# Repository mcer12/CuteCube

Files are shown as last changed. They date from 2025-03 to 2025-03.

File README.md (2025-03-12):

## About the project
This is a little cube toy with leds that changes color depending on which side it's laid on. Kids love it and it can be used for decision making (just kidding), desk games etc. It uses accelerometer to detect orientation and if you shake it, it does a random color animation. With 350mAh battery it lasts for about 2 weeks depending on use.  



## Important notes
- Letting toddlers play with this is at your own risk!
- you can use BMI055 or BMI088, make sure to select correct one in the sketch as they have different instruction sets
- Use my fork of the libraries to allow low power (gyro sleep):  
BMI088: https://github.com/mcer12/bmi088-arduino  
BMI055: https://github.com/mcer12/FastIMU  
- If you want to enable easy flashing via USB (serial), you need to set nBOOT_SEL fuse to 0: BOOT0 signal is defined by BOOT0 pin value (legacy mode)
- Forgive the code quality, it was a quick arduino project, not meant to be published and I'm NOT cleaning that up :D

## Printing notes
- No supports needed
- Transparent PLA or PETG highly recommended.
- Two size variants (55x55mm and 67x67mm)
- Requires two long M3 bols and two hot melt inserts.
- Bolts: I used 25mm 
- Inserts: OD4.5mm, 10mm length. You don't need to use inserts this long but they make it pretty much indestructible.

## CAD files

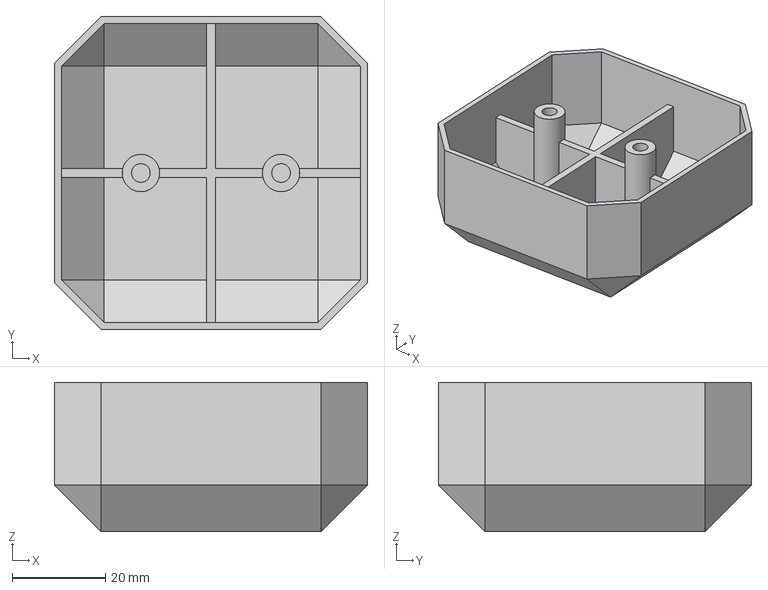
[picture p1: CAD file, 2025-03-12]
3D/cube_larger_bottom.3mf
67.0 x 67.0 x 32.0 mm

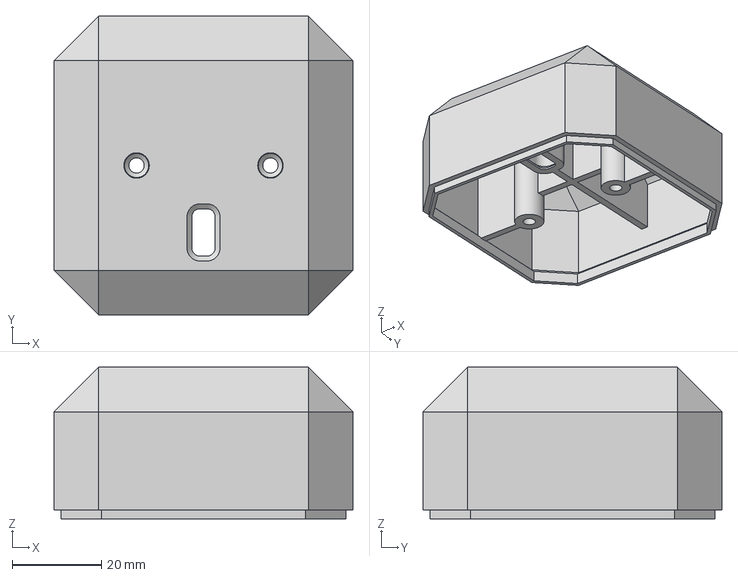
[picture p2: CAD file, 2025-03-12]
3D/cube_larger_top.3mf
67.0 x 67.0 x 34.0 mm

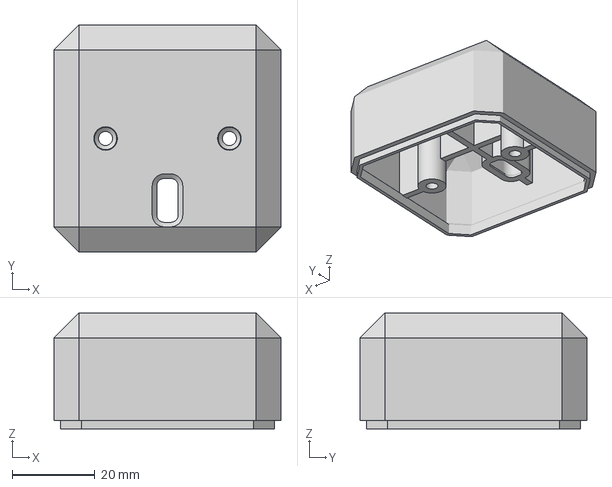
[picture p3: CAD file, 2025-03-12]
3D/cube_top.3mf
55.0 x 55.0 x 28.0 mm

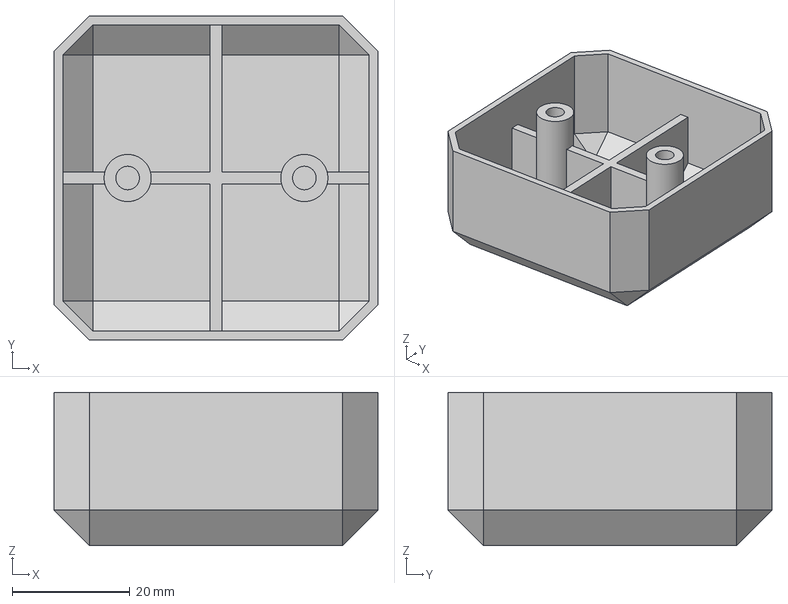
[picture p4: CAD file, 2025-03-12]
3D/cube_bottom.3mf
55.0 x 55.0 x 26.0 mm

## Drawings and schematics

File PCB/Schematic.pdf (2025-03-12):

TIM17: PA7, PA10, PD1, PB4, PB7, PB9,

## TIM16: PA6, PB6, PB8

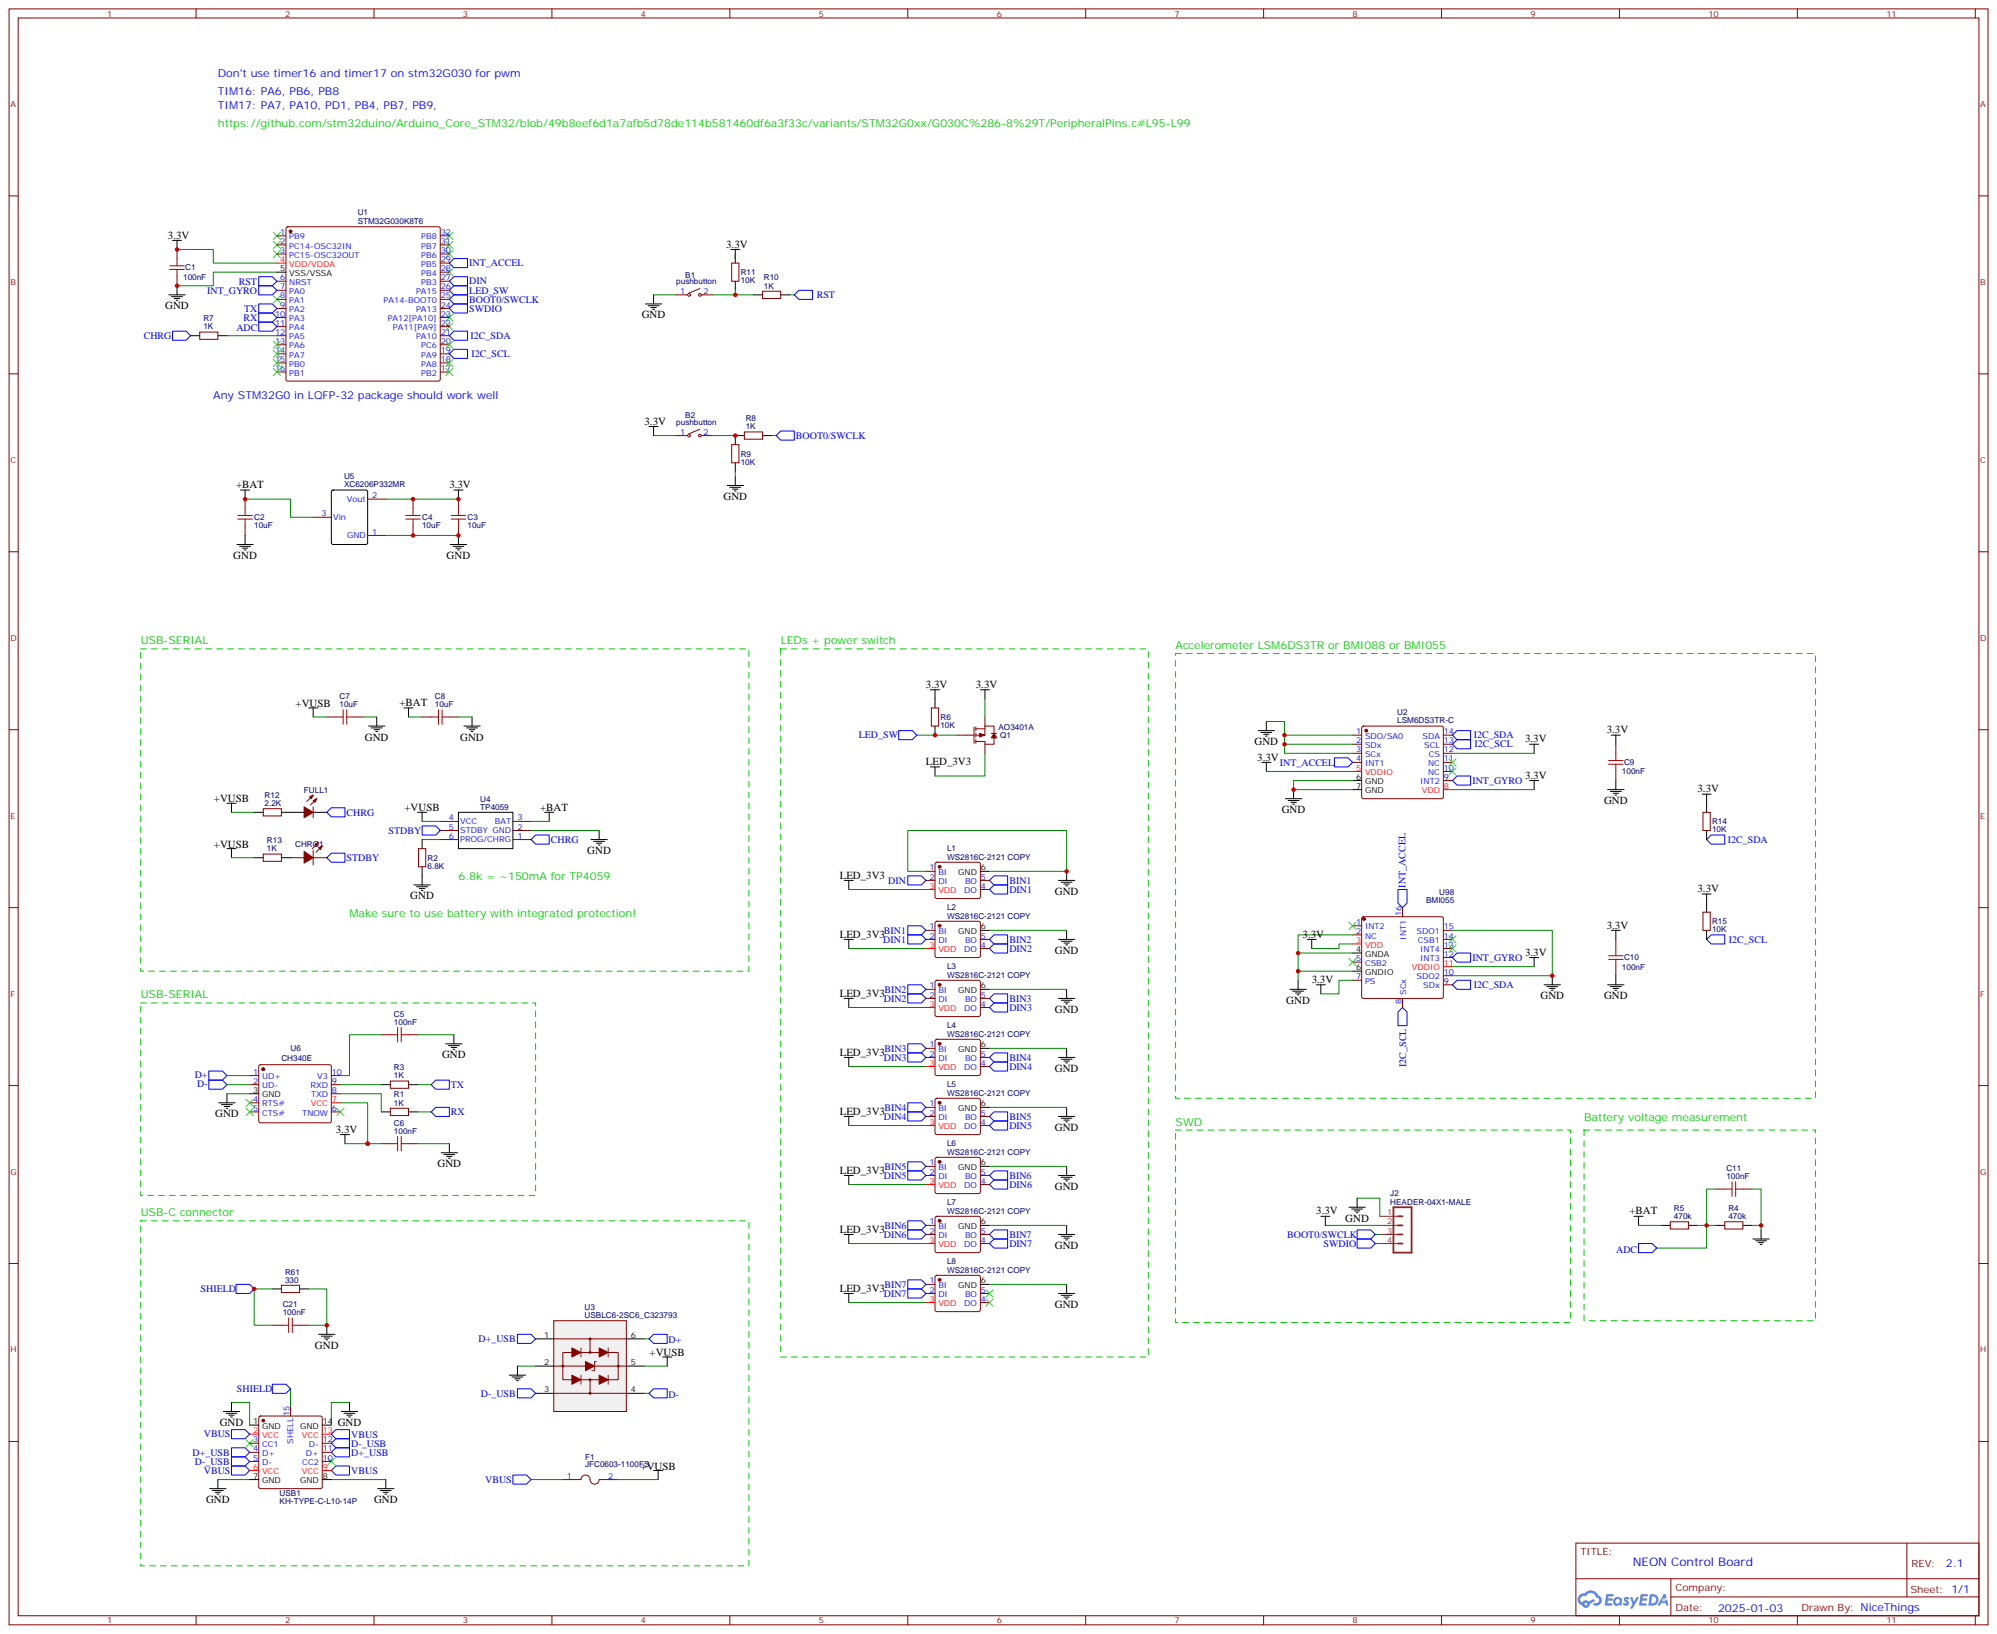
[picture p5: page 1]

Don't use timer16 and timer17 on stm32G030 for pwm

https://github.com/stm32duino/Arduino_Core_STM32/blob/49b8eef6d1a7afb5d78de114b581460df6a3f33c/variants/STM32G0xx/G030C%286-8%29T/PeripheralPins.c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

Any STM32G0 in LQFP-32 package should work well

Make sure to use battery with integrated protection!

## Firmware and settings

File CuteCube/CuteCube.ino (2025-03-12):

//#define USE_BMI088
#define DEBUG_ENABLE
#define ACCEL_ADDRESS 0x18
#define GYRO_ADDRESS 0x68
#define LED_PIN PB3
#define LED_EN PA15
#define NUM_LEDS 8
#define SLEEP_TIMEOUT_SECONDS 20
#define ADC_PIN PA4
#define CHRG_PIN PA5

#include <Wire.h>
#include "WS2816_Driver.h"
#include "STM32LowPower.h"

#ifdef USE_BMI088
#include "BMI088.h"
#else
#include "FastIMU.h"
#endif

#ifdef USE_BMI088
Bmi088Accel accel(Wire, ACCEL_ADDRESS);
Bmi088Gyro gyro(Wire, GYRO_ADDRESS);
#else
BMI055 IMU;
calData calib = { 0 };  //Calibration data
AccelData accelData;    //Sensor data
GyroData gyroData;
#endif

float accelX, accelY, accelZ, gyroX, gyroY, gyroZ, temp, voltage;
bool isCharging = false;
uint8_t orientation = 0;
unsigned long sleepTimer, shuffleTimer, shortShuffleTimer;
uint8_t shuffleCounter, shuffleCounterSuccess, shortShuffleCounter, shortShuffleCounterSuccess;
int bri = 40000;
int extraR = 0;
int extraG = 0;
int extraB = 0;
bool activity, wentToSleep = false;

WS2816_Driver strip(NUM_LEDS, LED_PIN);

void setup() {
  Serial.begin(115200);

  analogReadResolution(12);
  pinMode(ADC_PIN, INPUT);
  pinMode(CHRG_PIN, INPUT);
  pinMode(LED_EN, OUTPUT);
  setLedsPower(true);
  randomSeed(analogRead(ADC_PIN));
  delay(5);

  strip.begin();
  strip.clear();
  strip.show();

  delay(100);

  initSensor();

  LowPower.begin();
  sleepTimer = shuffleTimer = millis();

}


void loop() {
  readData();

  if (voltage < 3.4 && !wentToSleep) {
    handleLowBattery();
    setLedsPower(false);
#ifdef DEBUG_ENABLE
    Serial.println("low battery, going to sleep!");
    delay(20);
#endif
    LowPower.deepSleep(3000);
  }

  if (millis() - shuffleTimer > 100) {
    shuffleTimer = millis();
    shuffleCounter++;
    if (accelX > 20.0 || accelY > 20.0 || accelZ > 20.0) {
      shuffleCounterSuccess++;
    }
    if (shuffleCounter >= 10) {
      if (shuffleCounterSuccess >= 3) {
        handleShuffle();
        triggerActivity();
        orientation = -1;
      }
      shuffleCounter = shuffleCounterSuccess = 0;
    }
  }

  /*
    if (millis() - shortShuffleTimer > 50) {
      shortShuffleTimer = millis();
      shortShuffleCounter++;
      if (accelX > 15.0 || accelY > 15.0 || accelZ > 15.0) {
        shortShuffleCounterSuccess++;
      }
      if (shortShuffleCounter >= 30) {
        if (shortShuffleCounterSuccess >= 10) {
          handleShortShuffle();
        }
        shortShuffleCounter = shortShuffleCounterSuccess = 0;
      }
    }
  */

  if (accelX < -9.6 && orientation != 0) {
    orientation = 0;
    handleOrientation(orientation);
    triggerActivity();
    //strip.setPixelColor(0, 100, 0, 0);
    //strip.setPixelColor(1, 100, 0, 0);
    //strip.setPixelColor(2, 100, 0, 0);
    //strip.setPixelColor(3, 100, 0, 0);
  }
  if (accelX > 9.6 && orientation != 1) {
    orientation = 1;
    handleOrientation(orientation);
    triggerActivity();
    //strip.setPixelColor(4, 100, 0, 0);
    //strip.setPixelColor(5, 100, 0, 0);
    //strip.setPixelColor(6, 100, 0, 0);
    //strip.setPixelColor(7, 100, 0, 0);
  }
  if (accelY > 9.6 && orientation != 2) {
    orientation = 2;
    handleOrientation(orientation);
    triggerActivity();
    //strip.setPixelColor(0, 100, 0, 0);
    //strip.setPixelColor(1, 100, 0, 0);
    //strip.setPixelColor(6, 100, 0, 0);
    //strip.setPixelColor(7, 100, 0, 0);
  }
  if (accelY < -9.6 && orientation != 3) {
    orientation = 3;
    handleOrientation(orientation);
    triggerActivity();
    //strip.setPixelColor(2, 100, 0, 0);
    //strip.setPixelColor(3, 100, 0, 0);
    //strip.setPixelColor(4, 100, 0, 0);
    //strip.setPixelColor(5, 100, 0, 0);
  }
  if (accelZ > 9.6 && orientation != 4) {
    orientation = 4;
    handleOrientation(orientation);
    triggerActivity();
    //strip.setPixelColor(0, 100, 0, 0);
    //strip.setPixelColor(2, 100, 0, 0);
    //strip.setPixelColor(4, 100, 0, 0);
    //strip.setPixelColor(6, 100, 0, 0);
  }
  if (accelZ < -9.6 && orientation != 5) {
    orientation = 5;
    handleOrientation(orientation);
    triggerActivity();
    //strip.setPixelColor(1, 100, 0, 0);
    //strip.setPixelColor(3, 100, 0, 0);
    //strip.setPixelColor(5, 100, 0, 0);
    //strip.setPixelColor(7, 100, 0, 0);
  }


  if (millis() - sleepTimer > 30000) {
    //sleepTimer = millis();
    wentToSleep = true;
    setLedsPower(false);
#ifdef DEBUG_ENABLE
    Serial.println("no action, going to sleep!");
    delay(20);
#endif
    LowPower.deepSleep(3000);
  }

#ifdef DEBUG_ENABLE
  delay(10);
#else
  LowPower.deepSleep(20);
#endif

}

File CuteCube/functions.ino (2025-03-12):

void initSensor() {
#ifdef USE_BMI088
  int status;
  status = accel.begin();
  if (status < 0) {
    Serial.println("Accel Initialization Error");
    Serial.println(status);
    while (1) {}
  }
  status = gyro.begin();
  if (status < 0) {
    Serial.println("Gyro Initialization Error");
    Serial.println(status);
    while (1) {}
  }
  //accel.setMode(false);
  //accel.setPower(false);
  gyro.writeRegister(0x11, 0b10000000);
#else
  Wire.begin();
  Wire.setClock(400000); //400khz clock
  delay(300);
  int err = IMU.init(calib, ACCEL_ADDRESS);
  if (err != 0) {
    Serial.print("Error initializing IMU: ");
    Serial.println(err);
    while (true) {
      ;
    }
  }

  err = IMU.setGyroRange(2000);      //USE THESE TO SET THE RANGE, IF AN INVALID RANGE IS SET IT WILL RETURN -1
  err = IMU.setAccelRange(16);       //THESE TWO SET THE GYRO RANGE TO ±500 DPS AND THE ACCELEROMETER RANGE TO ±2g

  writeByteI2C(Wire, GYRO_ADDRESS, BMI055_GYR_LPM1, 0b10000000); // suspend mode for gyro
  //writeByteI2C(Wire, GYRO_ADDRESS, BMI055_GYR_LPM1, 0b00000000); // disable suspend mode for gyro



  if (err != 0) {
    Serial.print("Error Setting range: ");
    Serial.println(err);
    while (true) {
      ;
    }
  }
#endif
}

void readData() {
#ifdef USE_BMI088
  accel.readSensor();
  gyro.readSensor();
  accelX = accel.getAccelX_mss();
  accelY = accel.getAccelY_mss();
  accelZ = accel.getAccelZ_mss();
  gyroX = gyro.getGyroX_rads();
  gyroY = gyro.getGyroY_rads();
  gyroZ = gyro.getGyroZ_rads();
  isCharging = digitalRead(CHRG_PIN);
  //temp = accel.getTemperature_C();
#ifdef DEBUG_ENABLE
  Serial.print("BMI088, ");
#endif
#else
  IMU.update();
  IMU.getAccel(&accelData);
  IMU.getGyro(&gyroData);
  float constant = 0.61;
  accelX = accelData.accelX * constant;
  accelY = accelData.accelY * constant * -1.0;
  accelZ = accelData.accelZ * constant * -1.0;
  gyroX = gyroData.gyroX;
  gyroY = gyroData.gyroY;
  gyroZ = gyroData.gyroZ;
  //temp = IMU.getTemp();
#ifdef DEBUG_ENABLE
  Serial.print("BMI055, ");
#endif
#endif
  voltage = (movingAverageRead(ADC_PIN, 5) / 4096.0) * 2.0 * 3.3;
#ifdef DEBUG_ENABLE
  Serial.print(accelX);
  Serial.print(" = ax, ");
  Serial.print(accelY);
  Serial.print(" = ay, ");
  Serial.print(accelZ);
  Serial.print(" = az, ");
  Serial.print(gyroX);
  Serial.print(" = gx, ");
  Serial.print(gyroY);
  Serial.print(" = gy, ");
  Serial.print(gyroZ);
  Serial.print(" = gz, ");
  Serial.print(voltage);
  Serial.print(" = voltage, ");
  Serial.print(isCharging);
  Serial.print(" = chrg, ");

  //Serial.print(temp);
  Serial.print("\n");
#endif
}

void handleLowBattery() {
  clearTo(bri, 0, 0);
  strip.show();
  delay(500);
  clearTo(0, 0, 0);
  strip.show();
  delay(500);
  clearTo(bri, 0, 0);
  strip.show();
  delay(500);
  clearTo(0, 0, 0);
  strip.show();
  delay(500);
  clearTo(bri, 0, 0);
  strip.show();
  delay(500);
  clearTo(0, 0, 0);
  strip.show();
  delay(500);
}

void triggerActivity() {
  activity = true;
  wentToSleep = false;
  sleepTimer = millis();
}

int movingAverageRead(int analogPin, int numReadings) {
  int total = 0;
  for (int i = 0; i < numReadings; i++) {
    total += analogRead(analogPin);
  }
  return total / numReadings;
}

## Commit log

2025-03-12 Initial commit - arduino sketch, pcb fab files, schematic, easyeda source
    [PickAndPlace_CuteCube.csv]
2025-03-12 3D models added
    [cube_bottom.3mf, cube_larger_bottom.3mf, cube_larger_top.3mf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]
